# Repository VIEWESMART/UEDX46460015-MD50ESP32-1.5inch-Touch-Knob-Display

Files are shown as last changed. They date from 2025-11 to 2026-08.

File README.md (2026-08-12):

<h1 align = "center">UEDX46460015-MD50ESP32-1.5inch-Touch-Knob-Display</h1>

 * **[中文](./README_CN.md)**

<p align="center" width="90%">
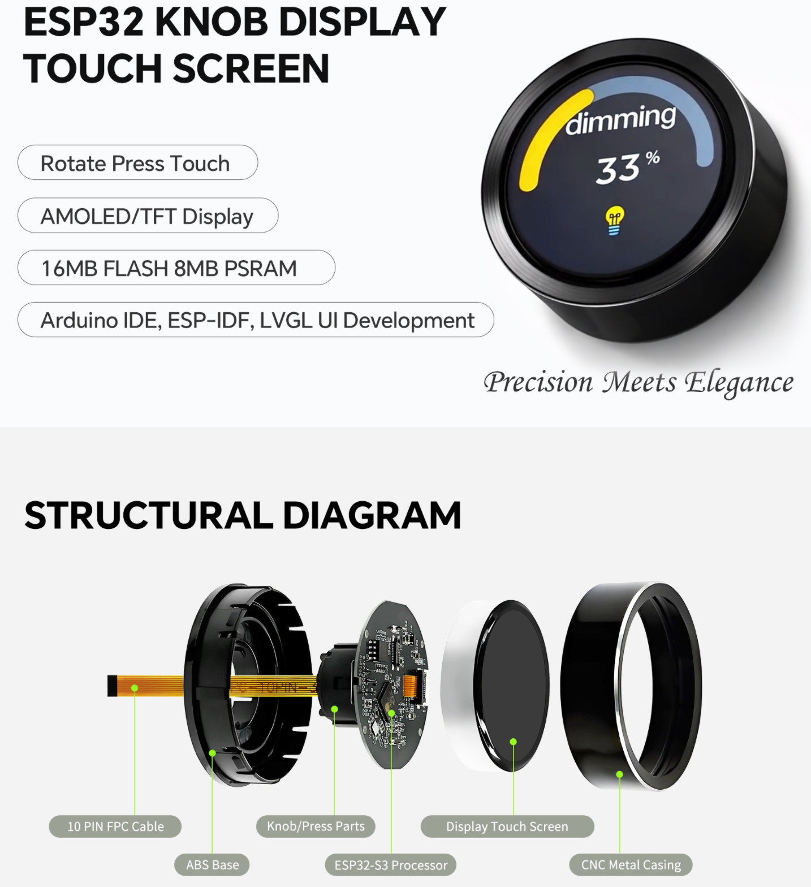
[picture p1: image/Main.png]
    
</p>

-   **UEDX46460015-MD50ET**
    ---
    The **Smart Knob Display** powered by **ESP32-S3**.  
    Featuring a 1.5-inch **466x466** AMOLED Display (QSPI), capacitive touch, rotary encoder and button.  
    Ideal for IoT control panels, smart home devices and industrial HMI.

## 1. Introduction

The **UEDX46460015-MD50ET** is a compact smart display module designed for knob‑style HMI applications.  
It combines a 1.5‑inch AMOLED display (466×466 pixels) with a capacitive touch panel, a rotary encoder and a hardware button.

Powered by the **ESP32‑S3‑R8** (16 MB Flash, 8 MB Octal PSRAM), it provides Wi‑Fi and Bluetooth 5 (LE) connectivity, and supports development with **Arduino**, **ESP‑IDF** and **PlatformIO**.

### 1.1 Product Features

* **Processor**:
    * **ESP32-S3**: Xtensa® Dual‑Core 32‑bit LX7 MCU @ 240 MHz.
    * Integrated 2.4 GHz Wi‑Fi (802.11 b/g/n) & Bluetooth 5 (LE).
* **Memory**:
    * **16 MB** Quad SPI Flash.
    * **8 MB** Octal SPI PSRAM.
* **Display & Touch**:
    * **Screen**: 1.5‑inch IPS AMOLED (466×466 Resolution).
    * **Interface**: QSPI.
    * **Driver IC**: CO5300AF‑42.
    * **Touch**: Capacitive Multi‑Touch (CST820) via I²C.
* **Peripherals**:
    * **Encoder**: Rotary encoder (PHA/PHB) for precise knob input.
    * **Button**: Hardware button (shared with BOOT).
    * **Connectivity**: USB‑C (USB/UART for programming and debugging), UART expansion (FPC).
    * **Expansion FPC**: Extra GPIO, 5V, GND, UART0.

### 1.2 Applications

* Smart Home Control Knobs
* Industrial Knob‑based HMI
* IoT Device Dials
* Wearable / Compact User Interfaces

---

## 2. Hardware Description

### 2.1 Module Overview

The main functional blocks of the board are:

| Component | Description |
| :--- | :--- |
| **ESP32‑S3‑R8** | Main SoC (16 MB Flash / 8 MB Octal PSRAM). |
| **1.5" AMOLED** | 466×466 pixel display driven by QSPI (CO5300AF‑42). |
| **CST820** | Capacitive touch controller (I²C). |
| **Rotary Encoder** | 2‑phase encoder (PHA/PHB) for knob rotation. |
| **Button** | BOOT button (also used for firmware download). |
| **USB‑C** | Programming, debug (UART via USB) and power (5V). |
| **FPC Connector** | Additional power, UART0 and UART2 signals. |

### 2.2 GPIO Definition (Pinout)

#### **Display (QSPI)**
| Display Pin | ESP32‑S3 Pin |
| :---: | :---: |
| CS | IO12 |
| PCLK | IO10 |
| DATA0 | IO13 |
| DATA1 | IO11 |
| DATA2 | IO14 |
| DATA3 | IO9 |
| RST | IO8 |
| BACKLIGHT | IO17 |

#### **Touch (CST820)**
| Touch Pin | ESP32‑S3 Pin |
| :---: | :---: |
| SDA | IO0 |
| SCL | IO1 |
| RST | IO3 |
| INT | IO4 |

#### **Button**
| Button Pin | ESP32‑S3 Pin |
| :---: | :---: |
| BOOT | IO0 |

#### **Encoder**
| Encoder Pin | ESP32‑S3 Pin |
| :---: | :---: |
| PHA | IO6 |
| PHB | IO5 |

#### **USB / UART**
| USB/UART Pin | ESP32‑S3 Pin |
| :---: | :---: |
| USB‑DN | IO19 |
| USB‑DP | IO20 |

#### **FPC Connector Pinout**
| FPC Pin | Adapter Signal | ESP32‑S3 Pin |
| :---: | :--- | :--- |
| 1 | 5V | 5V |
| 2 | PB7 | – |
| 3 | GND | GND |
| 4 | RX2 | GPIO40 |
| 5 | TX2 | GPIO39 |
| 6 | RX1 | U0RXD / GPIO44 |
| 7 | TX1 | U0TXD / GPIO43 |
| 8 | NC | CHIP‑EN |
| 9 | D+ (USB‑DP) | GPIO20 |
|10 | D‑ (USB‑DN) | GPIO19 |

### 2.3 Mechanical Dimensions

Refer to the product specification sheet for detailed dimensions.

---

## 3. Software

We provide comprehensive support for **Arduino**, **PlatformIO**, and **ESP‑IDF** frameworks, with pre‑ported **LVGL** examples.

### 3.1 Software Examples

Examples are available in the [GitHub Repository](https://github.com/VIEWESMART/ESP32-1.5inch-AMOLED-Knob) (examples folder).

| Framework | Example Path | Description |
| :---: | :--- | :--- |
| **Arduino** | `examples/arduino/gui/lvgl_v8` | **LVGL Benchmark**: Usage example of LVGL v8. Can be opened directly in Arduino IDE. |
| **ESP‑IDF** | `examples/esp_idf` | **LVGL port**: Example of porting and using LVGL in ESP‑IDF. |
| **PlatformIO** | `examples/platformio/lvgl_v8_port` | **LVGL v8 port**: Usage example of LVGL v8. |

### 3.2 Getting Started

#### 3.2.1 Preparation

* **Hardware**: UEDX46460015‑MD50ET Board, USB‑C Cable.
* **Software**: VS Code (ESP‑IDF v5.3+) or Arduino IDE (v2.0+) or VS Code (PlatformIO).
* **Libraries**: The following libraries are required for Arduino IDE and PlatformIO.

| Library | Version | Description |
| :--- | :--- | :--- |
| `ESP32_Display_Panel` | `1.0.3+` | By Espressif. Necessary to drive the screen. |
| `ESP32_IO_Expander` | *Arduino auto selection* | Dependency of `ESP32_Display_Panel`. |
| `esp-lib-utils` | *Arduino auto selection* | Dependency of `ESP32_Display_Panel`. |
| `lvgl` | `8.4.0` | Open‑source embedded graphics library. |

#### 3.2.2 ESP‑IDF Setup

For detailed procedures, please refer to the esp-idf example folder at [README.md](examples/ESP-IDF/UEDX46460015-MD50E-IDF/README.md) or [README_CN.md](examples/ESP-IDF/UEDX46460015-MD50E-IDF/README_CN.md). The general steps are as follows:

1.  **Open the example**  
    * Download the repository from GitHub (click the green "Code" button and select "Download ZIP", or clone it).  
    * Open the example folder (e.g., `examples/esp_idf`) using VS Code with the ESP‑IDF extension.
    
2.  **Compile and upload**  
    * Click the **build** icon to compile the project.  
    * Connect the board via USB‑C.  
    * Click the **upload** icon to flash the firmware.

#### 3.2.3 Arduino Setup([Novice tutorial](https://github.com/VIEWESMART/VIEWE-Tutorial/blob/main/Arduino%20Tutorial/Arduino%20Getting%20Started%20Tutorial.md))

1.  **Install Arduino IDE**  
    * Download and install the [Arduino IDE](https://www.arduino.cc/en/software) (v2.0+ recommended).

2.  **Install ESP32 Board Package**  
    * Open Arduino IDE and go to **File > Preferences**.  
    * Add the following URL in “Additional boards manager URLs”:  
      `https://espressif.github.io/arduino-esp32/package_esp32_index.json`  
    * Go to **Tools > Board > Boards Manager**, search for `esp32` by Espressif and install version **3.0.0+**.

3.  **Install Libraries**  
    * Go to **Sketch > Include Library > Library Manager**.  
    * Search for `ESP32_Display_Panel` by Espressif and install version **1.0.3+**. When prompted, click **INSTALL ALL** to install the dependencies.  
    * Install `lvgl` (version **8.4.0**).

4.  **Open Example**  
    * Navigate to **File > Examples > ESP32_Display_Panel**.  
    * Select **Arduino > gui > lvgl_v8 > simple_port**.

5.  **Select Board**  
    * Target: **ESP32S3 Dev Module**.  
    * Configure the following settings:
        * **Flash Size**: 16MB (128Mb)
        * **Partition Scheme**: 16M Flash (3MB APP/9.9MB FATFS)
        * **PSRAM**: **OPI PSRAM** (this is critical)

6.  **Configure the Supported Board**  
    * In the example, open the file `esp_panel_board_supported_conf.h`.  
    * Set the macro `ESP_PANEL_BOARD_DEFAULT_USE_SUPPORTED` to `1`.  
    * Locate the line `// #define BOARD_VIEWE_UEDX46460015_MD50ET` and uncomment it by removing the `//`.  
    * Ensure no other board definition is enabled at the same time.

7.  **Interface‑Specific Configuration**  
    * Since the board uses a **QSPI** interface, open `lv_conf.h` (or the example’s `lv_conf.h` equivalent) and set `LV_COLOR_16_SWAP` to `1`.  
    * **Do not** modify `LVGL_PORT_AVOID_TEARING_MODE` or `LVGL_PORT_ROTATION_DEGREE` (they are only relevant for RGB/MIPI displays).

8.  **Select Port and Upload**  
    * Connect the board, then go to **Tools > Port** and select the correct COM port.  
    * Click the **Verify** (✓) button to compile.  
    * Click the **Upload** (→) button to flash.

> [!TIP]
> **Configuration Tips**  
> * In `esp_panel_board_supported_conf.h`, ensure you uncomment: `#define BOARD_VIEWE_UEDX46460015_MD50ET`.  
> * Do not enable both `ESP_PANEL_BOARD_DEFAULT_USE_SUPPORTED` and `ESP_PANEL_BOARD_DEFAULT_USE_CUSTOM`.  
> * You cannot enable multiple board definitions at the same time.

#### 3.2.4 PlatformIO Setup

1.  **Open the example**  
    * Download the repository and open the `examples/platformio/lvgl_v8_port` folder in VS Code with the PlatformIO extension.

2.  **Select the Board Environment**  
    * Open the `platformio.ini` file.  
    * Change the `default_envs` line to `BOARD_VIEWE_UEDX46460015_MD50ET`.

3.  **Configure the Example**  
    * (QSPI interface) In `lv_conf.h`, set `LV_COLOR_16_SWAP` to `1`.  
    * Leave `LVGL_PORT_AVOID_TEARING_MODE` and `LVGL_PORT_ROTATION_DEGREE` untouched.

4.  **Compile and Upload**  
    * Click the **✓** (Compile) button.  
    * Connect the board, then click the **→** (Upload) button.
      
### 3.3 Firmware Download (Manual Flash)

If you need to flash a pre‑compiled binary manually:

1.  Open the “Flash Download Tool” (available in the tools folder or from Espressif’s website).
2.  Select the chip type (**ESP32‑S3**) and the correct download method.
3.  Load the firmware files from the `firmware` folder and configure the offsets as described in the firmware readme.
4.  Connect the board and start the download.  
    *If flashing fails, hold down the **BOOT** button while powering on, then retry.*

<p align="center" width="100%">
    example
    example
</p>

## FAQ

* Q. After reading the above tutorials, I still don't know how to build a programming environment. What should I do?
* A. If you still don't understand how to build an environment after reading the above tutorials, you can refer to the [VIEWE-FAQ]() document instructions to build it.

<br />

* Q. Why does Arduino IDE prompt me to update library files when I open it? Should I update them or not?
* A. Choose not to update library files. Different versions of library files may not be mutually compatible, so it is not recommended to update library files.

<br />

* Q. Why is there no serial data output on the "Uart" interface on my board? Is it defective and unusable?
* A. The default project configuration uses the USB interface as Uart0 serial output for debugging purposes. The "Uart" interface is connected to Uart0, so it won't output any data without configuration.<br />For PlatformIO users, please open the project file "platformio.ini" and modify the option under "build_flags = xxx" from "-D ARDUINO_USB_CDC_ON_BOOT=true" to "-D ARDUINO_USB_CDC_ON_BOOT=false" to enable external "Uart" interface.<br />For Arduino users, open the "Tools" menu and select "USB CDC On Boot: Disabled" to enable the external "Uart" interface.

<br />

* Q. Why is my board continuously failing to download the program?
* A. Please hold down the "BOOT" button and try downloading the program again.

## Information
[products specification](information/UEDX48480021-MD80E%20V3.3%20SPEC.pdf)

[Display Datasheet](information/UE021WV-RB40-L002B.pdf)

[button](information/6x6Silent%20switch.pdf)

[Encoder](information/C219783_%E6%97%8B%E8%BD%AC%E7%BC%96%E7%A0%81%E5%99%A8_EC28A1520401_%E8%A7%84%E6%A0%BC%E4%B9%A6_WJ239718.PDF)

[schematic](schematic/1.5%20MD50E%20SCH.V2.0_00.png)

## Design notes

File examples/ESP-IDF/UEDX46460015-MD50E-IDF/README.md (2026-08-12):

# UEDX46460015-MD50ET ESP-IDF Example

Open-source ESP-IDF example for the **UEDX46460015-MD50ET** 1.5" round AMOLED knob display (ESP32-S3): bring up LCD, touch, encoder/button, and run a SquareLine LVGL UI.

Board support is published as a registry BSP:

- BSP: [viewesmart/bsp_knob_15_md50et](https://components.espressif.com/components/viewesmart/bsp_knob_15_md50et) (`^1.0.2` recommended)
- Touch: [viewesmart/esp_lcd_touch_cst820](https://components.espressif.com/components/viewesmart/esp_lcd_touch_cst820) (pulled by the BSP)

[中文说明](./README_CN.md)

---

## Contents

1. [What you get](#what-you-get)
2. [Hardware](#hardware)
3. [Software setup (beginners)](#software-setup-beginners)
4. [Get this project](#get-this-project)
5. [Open and configure in VS Code](#open-and-configure-in-vs-code)
6. [First build](#first-build)
7. [Flash and monitor](#flash-and-monitor)
8. [What success looks like](#what-success-looks-like)
9. [Project layout](#project-layout)
10. [Dependencies](#dependencies)
11. [Application entry](#application-entry)
12. [Replace / edit the SquareLine UI](#replace--edit-the-squareline-ui)
13. [Choose LVGL 8 or 9](#choose-lvgl-8-or-9)
14. [Pinout](#pinout)
15. [BSP API summary](#bsp-api-summary)
16. [Troubleshooting](#troubleshooting)
17. [License and links](#license-and-links)

---

## What you get

After running this example you can:

- Show an LVGL UI on the 1.5" round AMOLED (demo UI included)
- Use the touchscreen
- Use the rotary encoder and the GPIO0 button
- Set panel brightness (0~100) through the BSP API

Verified with **ESP-IDF v5.5.4**, target **esp32s3**.

---

## Hardware

| Item | Spec |
|---|---|
| Module | UEDX46460015-MD50ET (folder name may say MD50E; same board family) |
| MCU | ESP32-S3 with **16 MB Flash + Octal PSRAM** (defaults assume this) |
| LCD | 1.5" round AMOLED, CO5300, QSPI |
| Touch | CST820, I2C |
| Input | Rotary encoder + button (GPIO0, often also Boot) |
| Cable | Data-capable USB cable |
| Host OS | Windows / macOS / Linux (steps below use Windows + VS Code) |

Display geometry (important):

| Use | Size |
|---|---|
| Driver / LVGL buffer | **472 x 466** |
| SquareLine design | **466 x 466** |
| `esp_lcd_panel_set_gap()` | **Do not use** |

---

## Software setup (beginners)

Recommended: **Visual Studio Code + Espressif IDF extension**, and install the toolchain with **EIM (ESP-IDF Installation Manager / Espressif Installation Manager)**. This is the current official flow and replaces the older "Configure ESP-IDF extension" wizard.

Official docs:

- [Install ESP-IDF and Tools (VS Code extension)](https://docs.espressif.com/projects/vscode-esp-idf-extension/en/latest/installation.html)
- [ESP-IDF Installation Manager](https://docs.espressif.com/projects/idf-im-ui/en/latest/)

### 1. Install VS Code

Download and install from [https://code.visualstudio.com/](https://code.visualstudio.com/).

### 2. Install the Espressif IDF extension

1. Open Extensions (`Ctrl+Shift+X` on Windows/Linux, `Shift+Command+X` on macOS).
2. Search for **ESP-IDF** or **Espressif IDF**.
3. Install the extension by **Espressif Systems**.
4. If a setup prompt appears, you can dismiss it and continue with EIM below.

### 3. Install ESP-IDF with EIM (>= 5.5)

EIM installs the ESP-IDF framework and required tools (compiler, CMake, Ninja, OpenOCD, etc.). After that, the VS Code extension auto-discovers installs via EIM's manifest file.

#### 3.1 Open EIM from VS Code (recommended)

1. Open the Command Palette (`Ctrl+Shift+P` / `Shift+Command+P`).
2. Run **ESP-IDF: Open ESP-IDF Installation Manager**.
3. Wait for the loading notification; EIM should start.
4. On a desktop machine, EIM usually opens as a **GUI** wizard—follow the on-screen steps.
5. Choose an **ESP-IDF version**:
   - This project needs **>= 5.5**
   - Recommended: **v5.5.4** (verified with this repo)
6. Pick an install path (short path, **no spaces**, ASCII preferred).
7. Confirm and wait for download/install (first run can take a while). In China, prefer Espressif download mirrors when offered.
8. Return to VS Code when finished.

#### 3.2 Select the active ESP-IDF version

If multiple versions are installed:

1. Command Palette -> **ESP-IDF: Select Current ESP-IDF Version**
2. Select the version for this project (for example **5.5.4**)
3. The extension stores the setup for the current workspace

> Default `eim_idf.json` locations: `C:\Espressif\tools\eim_idf.json` on Windows, `$HOME/.espressif/tools/eim_idf.json` on macOS/Linux. Usually no manual edit is needed; if discovery fails, check `idf.eimIdfJsonPath` in VS Code settings.

#### 3.3 Verify the install

1. Run **ESP-IDF: Doctor Command**
2. Fix any red errors before continuing
3. Confirm the status bar shows a valid ESP-IDF version

#### 3.4 Optional: install EIM standalone

You can also install EIM first, then use it to install ESP-IDF:

1. Open the [ESP-IDF Installation Manager docs / download](https://docs.espressif.com/projects/idf-im-ui/en/latest/)
2. Install EIM for your OS
3. Use EIM to install **ESP-IDF >= 5.5** (recommended **5.5.4**)
4. In VS Code, run **ESP-IDF: Select Current ESP-IDF Version** and pick that install

#### 3.5 Remote / headless note

In **SSH, WSL, Dev Containers, Codespaces**, or browser-based VS Code, the extension may run a terminal wizard (for example `eim wizard`) instead of the GUI. Follow the terminal prompts. See the official installation docs for details.

### 4. USB serial driver (Windows)

If no `COMx` port appears, install the USB-UART / USB-JTAG driver for your board (CP210x, CH340, Espressif USB-JTAG, etc.), then replug the cable.

---

## Get this project

**Option A: git clone**

```bash
git clone <this-repo-url>
cd UEDX46460015-MD50E-IDF
```

**Option B: Download ZIP**

1. GitHub -> **Code -> Download ZIP**.
2. Extract to a short ASCII path, e.g. `D:\work\UEDX46460015-MD50E-IDF`.
3. In VS Code, open that root folder (must contain `main/` and root `CMakeLists.txt`).

---

## Open and configure in VS Code

1. **File -> Open Folder...** and select the project root.
2. Trust the workspace if prompted.
3. Check the status bar for: ESP-IDF version, target **esp32s3**, and serial port.
4. Set target: Command Palette -> **ESP-IDF: Set Espressif device target** -> `esp32s3`.
5. Select port: **ESP-IDF: Select port to use**.

If you previously built for another target, delete `build/` before rebuilding.

---

## First build

### UI buttons

Click **Build** (or run **ESP-IDF: Build your project**).

The first build will:

1. Download dependencies into `managed_components/` from the ESP Component Registry
2. Compile IDF + LVGL + UI assets (can take several minutes)

Success ends with:

```text
Project build complete.
```

### CLI

```bash
cd /path/to/UEDX46460015-MD50E-IDF
idf.py set-target esp32s3
idf.py build
```

After a successful resolve you should see folders such as:

- `managed_components/viewesmart__bsp_knob_15_md50et`
- `managed_components/viewesmart__esp_lcd_touch_cst820`
- `managed_components/espressif__esp_lcd_co5300`
- `managed_components/espressif__esp_lvgl_adapter`
- `managed_components/lvgl__lvgl`

Do **not** hand-edit `managed_components/` or `dependencies.lock`.

---

## Flash and monitor

1. Connect USB and select the correct port.
2. If connect fails, hold **Boot** while starting flash (board-dependent).
3. Click **Flash**, then **Monitor** (or Flash and Monitor).

CLI example:

```bash
idf.py -p PORT flash monitor
```

Exit monitor: `Ctrl+]`.

---

## What success looks like

1. The round display shows the demo UI.
2. Serial log shows BSP init success (resolution / LVGL major).
3. Touch, encoder, and button interact with the UI.

If not, see [Troubleshooting](#troubleshooting).

---

## Project layout

```text
UEDX46460015-MD50E-IDF/
├── CMakeLists.txt
├── dependencies.lock           # auto-generated lockfile
├── partitions.csv              # custom table (~3MB factory)
├── sdkconfig / sdkconfig.defaults*
├── README.md / README_CN.md
├── main/
│   ├── CMakeLists.txt
│   ├── idf_component.yml       # pulls BSP + pins LVGL major
│   ├── main.c
│   └── ui/                     # SquareLine export
└── managed_components/         # downloaded deps (do not edit)
```

This example does **not** keep a local copy of the BSP under `components/`. It pulls `viewesmart/bsp_knob_15_md50et` from the registry.

---

## Dependencies

From `main/idf_component.yml`:

```yaml
dependencies:
  idf: ">=5.5"
  viewesmart/bsp_knob_15_md50et: "^1.0.2"
  lvgl/lvgl:
    version: "^8.3.11"
    public: true
```

`main/CMakeLists.txt` links the managed component as:

```cmake
REQUIRES
    viewesmart__bsp_knob_15_md50et
    lvgl
    esp_lvgl_adapter
```

---

## Application entry

See `main/main.c`:

```c
#include "bsp_knob_15_md50et.h"
#include "ui.h"

void app_main(void)
{
    bsp_knob_15_md50et_handles_t handles = {0};
    ESP_ERROR_CHECK(bsp_knob_15_md50et_init(&handles));

    bsp_knob_15_md50et_register_knob_cb(LVGL_knob_event);
    bsp_knob_15_md50et_register_button_cb(LVGL_button_event);

    if (bsp_knob_15_md50et_lock(-1) == ESP_OK) {
        ui_init();
        bsp_knob_15_md50et_unlock();
    }
}
```

Rules:

1. Call `bsp_knob_15_md50et_init()` first.
2. All LVGL calls must be between `lock` / `unlock`.
3. If a knob/button callback touches LVGL, lock there too.

Brightness:

```c
ESP_ERROR_CHECK(bsp_knob_15_md50et_set_brightness(80));  /* 0~100 */
```

---

## Replace / edit the SquareLine UI

1. Create/open a SquareLine project at **466 x 466**.
2. Use the same LVGL major as this repo (demo is **LVGL 8.x**).
3. Export into `main/ui/`.
4. `main/CMakeLists.txt` already compiles `ui/**/*.c`.
5. Do **not** shift widgets to "fix" centering; driver width is 472 and `set_gap` is unused.
6. Rebuild and flash.

If the app no longer fits flash, confirm custom `partitions.csv` (3MB `factory`) is enabled.

---

## Choose LVGL 8 or 9

The BSP accepts LVGL 8/9, but your UI must match one major.

```yaml
lvgl/lvgl:
  version: "^8.3.11"   # current demo
  # version: "^9"      # only if UI is exported for LVGL 9
  public: true
```

After switching majors, delete `managed_components/lvgl__lvgl`, `dependencies.lock`, and `build/`, then rebuild and replace `main/ui/`.

---

## Pinout

From `bsp_knob_15_md50et_board.h`:

| Function | GPIO |
|---|---|
| LCD CS / PCLK / D0-D3 | 12 / 10 / 13, 11, 14, 9 |
| LCD RST | 8 |
| Panel power (HIGH before LCD init) | 17 |
| Touch SCL / SDA / RST / INT | 3 / 1 / 2 / 4 |
| Encoder A / B | 6 / 5 |
| Button | 0 |

---

## BSP API summary

| API | Description |
|-----|---|
| `bsp_knob_15_md50et_init()` | Init power, LCD, touch, LVGL, knob, button |
| `bsp_knob_15_md50et_lock` / `unlock` | LVGL lock |
| `bsp_knob_15_md50et_set_brightness(0~100)` | Panel brightness (QSPI-safe) |
| `bsp_knob_15_md50et_backlight_on` / `off` | GPIO17 panel power |
| `bsp_knob_15_md50et_register_knob_cb` | Knob callback |
| `bsp_knob_15_md50et_register_button_cb` | Button callback |

Full docs:

- Registry: [viewesmart/bsp_knob_15_md50et](https://components.espressif.com/components/viewesmart/bsp_knob_15_md50et)
- Source: [GitHub bsp_knob_15_md50et](https://github.com/VIEWESMART/Viewe-esp32-components/tree/main/bsp/bsp_knob_15_md50et)

---

## Troubleshooting

### Environment / build

| Symptom | What to try |
|---|---|
| Cannot open EIM / Installation Manager | Update the **Espressif IDF** extension and reload VS Code; or install standalone [EIM](https://docs.espressif.com/projects/idf-im-ui/en/latest/) first |
| EIM download slow / failed | Switch network/proxy; prefer Espressif mirrors; allowlist Espressif install folders in antivirus |
| Extension cannot find installed IDF | Run **ESP-IDF: Select Current ESP-IDF Version**; check `eim_idf.json` or `idf.eimIdfJsonPath` |
| `idf.py` / extension not ready | Install IDF via EIM, then **ESP-IDF: Select Current ESP-IDF Version** and **ESP-IDF: Doctor Command**; use the extension IDF terminal |
| Stale config after target change | Delete `build/` and rebuild |
| Component not found / solve failed | Check registry access; confirm BSP version `^1.0.2` exists |
| button / adapter version conflict | Use BSP **>= 1.0.2**; delete `dependencies.lock` + `managed_components/` |
| App partition too small | Enable custom `partitions.csv` (3M factory) |
| First build very slow | Normal for LVGL + image assets |

### Flash / serial

| Symptom | What to try |
|---|---|
| No COM port | Data cable, USB driver, another port |
| Failed to connect | Hold Boot while flashing; close other serial apps |
| Monitor garbage | Match monitor baud rate (often 115200) |

### Display / touch / input

| Symptom | What to try |
|---|---|
| Black screen | Keep board CO5300 init table; GPIO17 is driven high before LCD init inside BSP |
| Left blank / right green line | Keep **472x466**, no `set_gap` |
| Brightness unchanged | Use `bsp_knob_15_md50et_set_brightness()`, do not raw-write `0x51` on QSPI |
| Touch dead | Check CST820 init logs / I2C |
| Knob/button dead | Ensure callbacks registered; lock before LVGL in callbacks |

### Clean rebuild

Delete:

```text
build/
managed_components/
dependencies.lock
```

Then:

```bash
idf.py set-target esp32s3
idf.py build
```

---

## License and links

- Example app code: see SPDX headers in source files (e.g. `main/main.c` is CC0-1.0)
- BSP / touch components: Apache-2.0 (see component repos)
- Other third-party components: their own licenses

Links:

- BSP: [viewesmart/bsp_knob_15_md50et](https://components.espressif.com/components/viewesmart/bsp_knob_15_md50et)
- Touch: [viewesmart/esp_lcd_touch_cst820](https://components.espressif.com/components/viewesmart/esp_lcd_touch_cst820)
- Component monorepo: [Viewe-esp32-components](https://github.com/VIEWESMART/Viewe-esp32-components)
- ESP-IDF docs: [https://docs.espressif.com/projects/esp-idf/](https://docs.espressif.com/projects/esp-idf/)
- VS Code install guide (EIM): [Install ESP-IDF and Tools](https://docs.espressif.com/projects/vscode-esp-idf-extension/en/latest/installation.html)
- EIM docs: [ESP-IDF Installation Manager](https://docs.espressif.com/projects/idf-im-ui/en/latest/)
- VS Code extension overview: [Espressif IDF Extension](https://docs.espressif.com/projects/vscode-esp-idf-extension/en/latest/)

Issues and PRs are welcome. If you are new to ESP-IDF, finish **setup -> build -> flash** once before changing the UI.

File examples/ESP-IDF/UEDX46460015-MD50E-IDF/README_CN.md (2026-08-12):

# UEDX46460015-MD50ET ESP-IDF 示例工程

本仓库是 **UEDX46460015-MD50ET**（1.5 寸圆形 AMOLED 旋钮屏，ESP32-S3）的开源示例，展示如何用 ESP-IDF 点亮屏幕、触摸、旋钮/按键，并运行 SquareLine 导出的 LVGL UI。

板级驱动已封装为组件仓库中的 BSP：

- BSP：[viewesmart/bsp_knob_15_md50et](https://components.espressif.com/components/viewesmart/bsp_knob_15_md50et)（建议 `^1.0.2`）
- 触摸：[viewesmart/esp_lcd_touch_cst820](https://components.espressif.com/components/viewesmart/esp_lcd_touch_cst820)（由 BSP 自动拉取）

[English](./README.md)

---

## 目录

1. [你能得到什么](#你能得到什么)
2. [硬件准备](#硬件准备)
3. [软件环境准备（新手必看）](#软件环境准备新手必看)
4. [获取本工程](#获取本工程)
5. [用 VS Code 打开并配置](#用-vs-code-打开并配置)
6. [第一次编译](#第一次编译)
7. [烧录与串口监视](#烧录与串口监视)
8. [成功时你会看到什么](#成功时你会看到什么)
9. [工程目录说明](#工程目录说明)
10. [依赖说明](#依赖说明)
11. [示例代码入口](#示例代码入口)
12. [替换 / 修改 SquareLine UI](#替换--修改-squareline-ui)
13. [选择 LVGL 8 或 9](#选择-lvgl-8-或-9)
14. [引脚一览](#引脚一览)
15. [BSP API 摘要](#bsp-api-摘要)
16. [常见问题排查](#常见问题排查)
17. [许可证与相关链接](#许可证与相关链接)

---

## 你能得到什么

跑通本示例后，你可以：

- 在 1.5" 圆形 AMOLED 上显示 LVGL 界面（本仓库自带演示 UI）
- 使用触摸屏点按 UI
- 使用旋钮左右旋转、按键（GPIO0）触发 UI 事件
- 通过 BSP API 调节面板亮度（0~100）

本工程已在 **ESP-IDF v5.5.4**、目标芯片 **esp32s3** 上验证。

---

## 硬件准备

| 项目 | 说明 |
|---|---|
| 模组 | UEDX46460015-MD50ET（文件夹名可能写作 MD50E，指同一款板） |
| MCU | ESP32-S3，**16 MB Flash + Octal PSRAM**（本工程默认按此配置） |
| 屏幕 | 1.5" 圆形 AMOLED，驱动芯片 CO5300，接口 QSPI |
| 触摸 | CST820，I2C |
| 输入 | 旋转编码器 + 按键（GPIO0，通常也是 Boot 键） |
| 数据线 | 能传数据的 USB 线（仅充电线无法下载） |
| 电脑 | Windows / macOS / Linux 均可（下文以 Windows + VS Code 为例） |

显示分辨率约定（很重要，改错会出现绿边/留白）：

| 用途 | 分辨率 |
|---|---|
| 驱动 / LVGL 显示缓冲 | **472 × 466** |
| SquareLine 工程设计尺寸 | **466 × 466** |
| `esp_lcd_panel_set_gap()` | **不要调用** |

---

## 软件环境准备（新手必看）

推荐使用 **Visual Studio Code + Espressif IDF 扩展**，并通过 **EIM（ESP-IDF Installation Manager / Espressif Installation Manager）** 安装 ESP-IDF 与工具链。这是当前官方推荐方式，比旧的 “Configure ESP-IDF extension” 向导更统一、更稳定。

官方说明可参考：

- [Install ESP-IDF and Tools（VS Code 扩展文档）](https://docs.espressif.com/projects/vscode-esp-idf-extension/en/latest/installation.html)
- [ESP-IDF Installation Manager](https://docs.espressif.com/projects/idf-im-ui/en/latest/)

### 1. 安装 VS Code

1. 打开 [https://code.visualstudio.com/](https://code.visualstudio.com/) 下载并安装。
2. 安装完成后打开 VS Code。

### 2. 安装 Espressif IDF 扩展

1. 左侧点 **扩展（Extensions）**，或按 `Ctrl+Shift+X`（macOS：`Shift+Command+X`）。
2. 搜索 **ESP-IDF** 或 **Espressif IDF**。
3. 安装发布者名为 **Espressif Systems** 的扩展。
4. 安装完成后如弹出配置提示，可先关闭，下一步用 EIM 正式安装。

### 3. 用 EIM 安装 ESP-IDF（>= 5.5）

EIM 会安装 ESP-IDF 框架以及编译/烧录所需工具（编译器、CMake、Ninja、OpenOCD 等）。装好后，VS Code 扩展会自动读取 EIM 生成的清单文件并发现已安装版本。

#### 3.1 从 VS Code 打开 EIM（推荐）

1. 按 `Ctrl+Shift+P`（macOS：`Shift+Command+P`）打开命令面板。
2. 输入并选择：**ESP-IDF: Open ESP-IDF Installation Manager**。
3. 稍等片刻，会看到加载提示，随后启动 EIM。
4. 在桌面环境下，EIM 通常以 **图形界面（GUI）** 打开；按窗口提示一步步操作即可。
5. 选择要安装的 **ESP-IDF 版本**：
   - 本工程要求 **>= 5.5**
   - 建议安装 **v5.5.4**（本仓库验证版本）
6. 按提示选择安装路径（路径尽量短、**不要有空格**、尽量纯英文）。
7. 确认后开始下载与安装。首次安装可能较久，请保持网络畅通；国内网络可优先使用乐鑫下载源（若 EIM / 文档提供 Download 选项）。
8. 安装完成后再回到 VS Code。

#### 3.2 选择当前使用的 ESP-IDF 版本

若你安装了多个版本：

1. 命令面板执行：**ESP-IDF: Select Current ESP-IDF Version**
2. 在列表中选择本工程要用的版本（例如 **5.5.4**）
3. 扩展会把当前工程需要的环境变量配置好

> Windows 上 EIM 清单默认通常在 `C:\Espressif\tools\eim_idf.json`；macOS/Linux 通常在 `$HOME/.espressif/tools/eim_idf.json`。一般无需手改；若扩展找不到安装，可在 VS Code 设置里检查 `idf.eimIdfJsonPath`。

#### 3.3 检查安装是否正常

1. 命令面板执行：**ESP-IDF: Doctor Command**
2. 查看输出，确认没有红色错误
3. 也可看 VS Code 状态栏是否显示已识别的 ESP-IDF 版本

#### 3.4 可选：单独下载 EIM

如果不想从扩展内启动，也可以先安装独立版 EIM，再用它安装 ESP-IDF：

1. 打开 [ESP-IDF Installation Manager 文档 / 下载页](https://docs.espressif.com/projects/idf-im-ui/en/latest/)
2. 按系统选择安装方式（Windows / macOS / Linux；也可用包管理器或直接下载）
3. 运行 EIM，安装 **ESP-IDF >= 5.5**（建议 5.5.4）
4. 回到 VS Code，执行 **ESP-IDF: Select Current ESP-IDF Version** 选中刚装的版本

#### 3.5 远程 / 无界面环境说明

若你在 **SSH、WSL、Dev Containers、Codespaces** 等环境中使用 VS Code，扩展可能无法弹出 EIM 图形界面，而会改走终端向导（例如 `eim wizard`）。按终端提示选择版本并完成安装即可。详见官方安装文档。

### 4. 准备驱动（Windows 常见）

- 多数板子使用板载 USB-UART 或 USB-JTAG。
- 若设备管理器里没有端口（`COMx`），请安装对应 USB 驱动（常见为 Silicon Labs CP210x、WCH CH340、或乐鑫 USB-JTAG 驱动）。
- 安装后重新插拔 USB，确认出现 `COMx`。

---

## 获取本工程

任选一种方式：

**方式 A：Git 克隆（推荐）**

```bash
git clone <本仓库地址>
cd UEDX46460015-MD50E-IDF
```

**方式 B：下载 ZIP**

1. 在 GitHub 页面点击 **Code -> Download ZIP**。
2. 解压到不包含中文空格特殊符号的路径，例如：`D:\work\UEDX46460015-MD50E-IDF`。
3. 用 VS Code 打开解压后的**根目录**（能看到 `main/` 和根目录 `CMakeLists.txt`）。

> 路径尽量短、纯英文，可减少 Windows 下路径过长导致的编译问题。

---

## 用 VS Code 打开并配置

### 1. 打开文件夹

1. VS Code：**文件 -> 打开文件夹...**
2. 选择本工程根目录。
3. 若提示“是否信任”，选择信任。

### 2. 确认状态栏三项

打开后，底部状态栏应能看到类似信息：

1. **ESP-IDF 版本**（如 5.5.4）
2. **目标芯片**：必须是 `esp32s3`
3. **串口**：如 `COM5`（插上板子后选择）

### 3. 设置目标芯片（第一次很重要）

1. `Ctrl+Shift+P`
2. 选择：**ESP-IDF: Set Espressif device target**
3. 选择 **esp32s3**
4. 等待配置完成（会生成/更新 `sdkconfig`）

> 若以前用别的芯片编译过，切换 target 后建议删掉 `build/` 再编译。

### 4. 选择串口

1. `Ctrl+Shift+P`
2. 选择：**ESP-IDF: Select port to use**
3. 选中板子对应的 `COMx`

---

## 第一次编译

### 图形界面（推荐）

1. 点击 VS Code 底部或侧边的 **Build**（🔧图标），或命令面板执行 **ESP-IDF: Build your project**。
2. 第一次编译会做两件耗时的事：
   - 从 [ESP Component Registry](https://components.espressif.com/) 下载依赖到 `managed_components/`
   - 编译 IDF + LVGL + UI 资源（可能 3 分钟左右，取决于电脑）
3. 成功时终端末尾会出现类似：

```text
Project build complete.
```

### 命令行方式

在已 `export` ESP-IDF 环境的终端中：

```bash
cd /path/to/UEDX46460015-MD50E-IDF
idf.py set-target esp32s3
idf.py build
```

### 第一次编译常见现象（正常）

| 现象 | 说明 |
|---|---|
| 提示 Solving dependencies / Processing dependencies | 正在解析并下载组件，请等待 |
| 生成 `managed_components/`、`dependencies.lock` | 正常，**不要手改**这些内容 |
| 下载很慢或超时 | 检查网络；可稍后重试 `idf.py build` |

成功拉取后，你应能在 `managed_components/` 看到例如：

- `viewesmart__bsp_knob_15_md50et`
- `viewesmart__esp_lcd_touch_cst820`
- `espressif__esp_lcd_co5300`
- `espressif__esp_lvgl_adapter`
- `espressif__button` / `espressif__knob`
- `lvgl__lvgl`

---

## 烧录与串口监视

### 烧录前检查

1. USB 已连接，串口已选对。
2. 若烧录时提示连接失败：按住板上 **Boot** 键再点烧录，或进入下载模式后再松手（视硬件而定）。
3. 关闭占用串口的其他软件（串口助手、旧 Monitor 等）。

### 图形界面

1. 点击 **Flash（⚡）** 烧录。
2. 点击 **Monitor（显示器图标）** 打开串口日志。
3. 也可使用组合按钮 **Flash and Monitor（火苗图标）**。

### 命令行

把 `PORT` 换成你的串口，例如 Windows 的 `COM5`，Linux 的 `/dev/ttyUSB0`：

```bash
idf.py -p PORT flash monitor
```

退出监视器：`Ctrl+]`。

---

## 成功时你会看到什么

1. 屏幕点亮，显示本仓库演示 UI（SquareLine 界面）。
2. 串口日志中有 BSP 初始化成功信息（含分辨率、LVGL 版本等）。
3. 触摸可点击；旋钮左右转、按键可触发 UI 中对应逻辑。

若黑屏 / 花屏 / 无触摸，请先看文末 [常见问题排查](#常见问题排查)。

---

## 工程目录说明

```text
UEDX46460015-MD50E-IDF/
├── CMakeLists.txt              # 工程入口 CMake
├── dependencies.lock           # 组件版本锁定（自动生成，勿手改）
├── partitions.csv              # 自定义分区表（factory 约 3MB）
├── sdkconfig                   # 本地当前配置（编译后生成/修改）
├── sdkconfig.defaults          # 默认配置（LVGL、分区表等）
├── sdkconfig.defaults.esp32s3  # ESP32-S3：Flash/PSRAM 等
├── README.md                   # 英文说明
├── README_CN.md                # 中文说明（本文件）
├── main/                       # 应用代码
│   ├── CMakeLists.txt          # 编译 main.c + ui 源文件
│   ├── idf_component.yml       # 声明 BSP / LVGL 等依赖
│   ├── main.c                  # app_main 入口
│   └── ui/                     # SquareLine 导出的 UI
│       ├── ui.c / ui.h
│       ├── screens/
│       ├── images/
│       └── ...
└── managed_components/         # 组件管理器自动下载（勿手改，可删后重建）
    ├── viewesmart__bsp_knob_15_md50et/
    ├── viewesmart__esp_lcd_touch_cst820/
    └── ...
```

说明：

- **不要**把 BSP 再复制一份到 `components/`，除非你明确要改 BSP 源码做本地调试。
- 本示例已通过 `main/idf_component.yml` 从注册表拉取 BSP。

---

## 依赖说明

`main/idf_component.yml` 关键内容大致如下：

```yaml
dependencies:
  idf: ">=5.5"
  viewesmart/bsp_knob_15_md50et: "^1.0.2"
  lvgl/lvgl:
    version: "^8.3.11"   # 与当前演示 UI（LVGL 8）匹配
    public: true
```

| 依赖 | 作用 |
|---|---|
| `viewesmart/bsp_knob_15_md50et` | 板级初始化：LCD / 触摸 / LVGL adapter / 旋钮 / 按键 / 亮度 |
| `lvgl/lvgl` | GUI 库（主版本必须与 UI 导出一致） |
| BSP 传递依赖 | CO5300、CST820、`esp_lvgl_adapter`、`button`、`knob` 等会自动下载 |

`main/CMakeLists.txt` 中通过下面名称链接 managed 组件（双下划线是命名空间规则）：

```cmake
REQUIRES
    viewesmart__bsp_knob_15_md50et
    lvgl
    esp_lvgl_adapter
```

---

## 示例代码入口

核心逻辑在 `main/main.c`：

```c
#include "bsp_knob_15_md50et.h"
#include "ui.h"

void app_main(void)
{
    bsp_knob_15_md50et_handles_t handles = {0};
    ESP_ERROR_CHECK(bsp_knob_15_md50et_init(&handles));

    bsp_knob_15_md50et_register_knob_cb(LVGL_knob_event);
    bsp_knob_15_md50et_register_button_cb(LVGL_button_event);

    if (bsp_knob_15_md50et_lock(-1) == ESP_OK) {
        ui_init();
        bsp_knob_15_md50et_unlock();
    }
}
```

规则：

1. 先 `bsp_knob_15_md50et_init()`。
2. 所有 LVGL API（含 `ui_init()`、改控件）必须夹在 `lock` / `unlock` 之间。
3. 旋钮/按键回调里如果要操作 LVGL，同样先 `lock`。

调节亮度示例：

```c
ESP_ERROR_CHECK(bsp_knob_15_md50et_set_brightness(80));  /* 0~100 */
```

---

## 替换 / 修改 SquareLine UI

1. 打开 SquareLine Studio，新建或打开工程，分辨率设为 **466 × 466**。
2. LVGL 版本选择与本工程一致（当前示例为 **LVGL 8.x**）。
3. 导出到 `main/ui/`（覆盖生成文件时注意保留你自己改过的事件文件，如有）。
4. 本工程 `main/CMakeLists.txt` 已用通配符编译 `ui/**/*.c`，一般无需改 CMake。
5. **不要**为了“居中对齐”去整体平移控件坐标：驱动宽度是 472，且不使用 `set_gap`；SquareLine 继续按 466×466 设计即可。
6. 重新 `build` / `flash`。

若 UI 资源变大导致烧录报分区不足：确认 `sdkconfig` 使用了自定义 `partitions.csv`（本仓库默认 `factory` 为 **3MB**）。

---

## 选择 LVGL 8 或 9

BSP 支持 LVGL 8/9，但**应用 UI 只能选一个主版本**。

在 `main/idf_component.yml`：

```yaml
lvgl/lvgl:
  version: "^8.3.11"   # 当前演示 UI
  # version: "^9"      # 仅当你的 UI 按 LVGL 9 导出时启用
  public: true
```

切换主版本后建议：

1. 删除 `managed_components/lvgl__lvgl`
2. 删除 `dependencies.lock`
3. 删除 `build/`
4. 重新 `idf.py set-target esp32s3`（如需要）并 `idf.py build`
5. 同步替换 `main/ui/` 为对应主版本导出的代码

---

## 引脚一览

定义在 BSP 头文件 `bsp_knob_15_md50et_board.h`（位于 managed 组件 include 目录）：

| 功能 | GPIO |
|---|---|
| LCD CS | 12 |
| LCD PCLK | 10 |
| LCD D0 / D1 / D2 / D3 | 13 / 11 / 14 / 9 |
| LCD RST | 8 |
| 面板供电（须在 LCD init 前为高） | 17 |
| 触摸 SCL / SDA | 3 / 1 |
| 触摸 RST / INT | 2 / 4 |
| 编码器 A / B | 6 / 5 |
| 按键 | 0 |

---

## BSP API 摘要

| API | 说明 |
|-----|---|
| `bsp_knob_15_md50et_init()` | 初始化供电、LCD、触摸、LVGL、旋钮、按键 |
| `bsp_knob_15_md50et_lock` / `unlock` | LVGL 线程安全锁 |
| `bsp_knob_15_md50et_set_brightness(0~100)` | 面板亮度（QSPI 下请用此 API） |
| `bsp_knob_15_md50et_backlight_on` / `off` | GPIO17 面板供电开关 |
| `bsp_knob_15_md50et_register_knob_cb` | 旋钮回调（`KNOB_LEFT` / `KNOB_RIGHT`） |
| `bsp_knob_15_md50et_register_button_cb` | 按键回调（按下/抬起/长按保持） |

更完整的说明见组件文档：

- 注册表：[viewesmart/bsp_knob_15_md50et](https://components.espressif.com/components/viewesmart/bsp_knob_15_md50et)
- 源码：[GitHub bsp_knob_15_md50et](https://github.com/VIEWESMART/Viewe-esp32-components/tree/main/bsp/bsp_knob_15_md50et)

---

## 常见问题排查

### A. 环境 / 编译类

| 现象 | 处理建议 |
|---|---|
| 打不开 EIM / Installation Manager | 确认已安装最新 **Espressif IDF** 扩展；更新扩展后重开 VS Code；也可先装独立版 [EIM](https://docs.espressif.com/projects/idf-im-ui/en/latest/) |
| EIM 下载很慢或失败 | 换网络 / 代理；优先使用乐鑫下载源；杀毒软件放行 Espressif 安装目录 |
| 扩展找不到已安装的 IDF | 执行 **ESP-IDF: Select Current ESP-IDF Version**；检查 `eim_idf.json` 或设置 `idf.eimIdfJsonPath` |
| 找不到 `idf.py` / 扩展未激活 | 用 EIM 安装 IDF 后执行 **ESP-IDF: Select Current ESP-IDF Version**，再跑 **ESP-IDF: Doctor Command**；用扩展自带的 IDF 终端 |
| `Set target` 后编译错误残留 | 删除 `build/` 再编译 |
| `Version solving failed` / 找不到组件 | 检查网络能否访问 components.espressif.com；确认 `main/idf_component.yml` 中 BSP 版本存在（如 `^1.0.2`） |
| 依赖冲突（button / adapter 版本） | 使用 BSP **>= 1.0.2**；删除 `dependencies.lock` 与 `managed_components/` 后重编 |
| 编译报 app 太大 / 分区不够 | 确认启用自定义分区 `partitions.csv`（3M factory） |
| 第一次特别慢 | 正常；LVGL + 图片资源编译耗时 |

### B. 烧录 / 串口类

| 现象 | 处理建议 |
|---|---|
| 没有 COM 口 | 换数据线、装 USB 驱动、换 USB 口 |
| `Failed to connect` | 按住 Boot 再烧录；确认波特率/驱动；关闭占用串口的程序 |
| Monitor 乱码 | 确认监视波特率与工程一致（常见 115200） |

### C. 显示 / 触摸 / 输入类

| 现象 | 处理建议 |
|---|---|
| 黑屏 | 确认是本板固件；GPIO17 已在 BSP 内于 LCD init 前拉高；勿替换掉板级 CO5300 初始化表 |
| 左边留白 / 右边绿线 | 驱动分辨率保持 **472×466**，**不要** `set_gap` |
| 亮度没变化 | 调用 `bsp_knob_15_md50et_set_brightness()`，不要对 QSPI 直接写 `0x51` |
| 触摸无反应 | 查看日志是否 CST820 初始化失败；检查 I2C 接线/模组型号 |
| 旋钮/按键无反应 | 确认已 `register_*_cb`；回调里操作 LVGL 前先 `lock` |

### D. 想“干净重来”

在工程根目录删除后重编（会重新下载组件）：

```text
build/
managed_components/
dependencies.lock
```

然后：

```bash
idf.py set-target esp32s3
idf.py build
```

---

## 许可证与相关链接

- 示例应用代码：见各源文件 SPDX（如 `main/main.c` 为 CC0-1.0）
- BSP / 触摸组件：Apache-2.0（以组件仓库为准）
- 第三方组件：遵循各自许可证

相关链接：

- BSP 组件：[viewesmart/bsp_knob_15_md50et](https://components.espressif.com/components/viewesmart/bsp_knob_15_md50et)
- 触摸组件：[viewesmart/esp_lcd_touch_cst820](https://components.espressif.com/components/viewesmart/esp_lcd_touch_cst820)
- 组件源码单仓：[Viewe-esp32-components](https://github.com/VIEWESMART/Viewe-esp32-components)
- ESP-IDF 编程指南：[https://docs.espressif.com/projects/esp-idf/](https://docs.espressif.com/projects/esp-idf/)
- VS Code 插件安装（含 EIM）：[Install ESP-IDF and Tools](https://docs.espressif.com/projects/vscode-esp-idf-extension/en/latest/installation.html)
- EIM 文档：[ESP-IDF Installation Manager](https://docs.espressif.com/projects/idf-im-ui/en/latest/)
- VS Code 插件总览：[Espressif IDF Extension](https://docs.espressif.com/projects/vscode-esp-idf-extension/en/latest/)

欢迎 Issue / PR。若你是第一次接触 ESP-IDF，建议先完整走通本文“环境准备 -> 编译 -> 烧录”三步，再开始改 UI。

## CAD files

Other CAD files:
2D drawings/UEDX46460015-MD50E.dwg

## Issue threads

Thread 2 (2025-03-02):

User data should be placed in SRAM

par-n-go, 2025-03-02:
Following your instructions on how to port and upload the code through the arduino IDE I get this error while trying to compile an example:

```
c:\Projects\screen_test\libraries\ESP32_Display_Panel-bugfix-missing_lcd_load_vendor_config\src\lcd\ESP_PanelLcd.cpp:457:109: error: macro "ESP_PANEL_CHECK_FALSE_RET" requires 4 arguments, but only 1 given
  457 |         ESP_PANEL_CHECK_FALSE_RET((esp_ptr_internal(user_data), false, "User data should be placed in SRAM"));
      |                                                                                                             ^
In file included from c:\Projects\screen_test\libraries\ESP32_Display_Panel-bugfix-missing_lcd_load_vendor_config\src\lcd\ESP_PanelLcd.cpp:9:
c:\Projects\screen_test\libraries\ESP32_Display_Panel-bugfix-missing_lcd_load_vendor_config\src/ESP_PanelLog.h:58: note: macro "ESP_PANEL_CHECK_FALSE_RET" defined here
   58 | #define ESP_PANEL_CHECK_FALSE_RET(x, ret, fmt, ...) do {         \
      |
c:\Projects\screen_test\libraries\ESP32_Display_Panel-bugfix-missing_lcd_load_vendor_config\src\lcd\ESP_PanelLcd.cpp: In member function 'bool ESP_PanelLcd::attachRefreshFinishCallback(std::function<bool(void*)>, void*)':
c:\Projects\screen_test\libraries\ESP32_Display_Panel-bugfix-missing_lcd_load_vendor_config\src\lcd\ESP_PanelLcd.cpp:454:29: error: cannot convert 'std::function<bool(void*)>' to 'const void*'
  454 |             esp_ptr_in_iram(callback), false,
      |                             ^~~~~~~~
      |                             |
      |                             std::function<bool(void*)>
c:\Projects\screen_test\libraries\ESP32_Display_Panel-bugfix-missing_lcd_load_vendor_config\src/ESP_PanelLog.h:59:14: note: in definition of macro 'ESP_PANEL_CHECK_FALSE_RET'
   59 |         if ((x) == false) {                                      \
      |              ^
In file included from C:\Users\valer\AppData\Local\Arduino15\packages\esp32\tools\esp32-arduino-libs\idf-release_v5.3-489d7a2b-v1\esp32s3/include/freertos/FreeRTOS-Kernel/portable/xtensa/include/freertos/portmacro.h:54,
                 from C:\Users\valer\AppData\Local\Arduino15\packages\esp32\tools\esp32-arduino-libs\idf-release_v5.3-489d7a2b-v1\esp32s3/include/freertos/FreeRTOS-Kernel/include/freertos/portable.h:57,
                 from C:\Users\valer\AppData\Local\Arduino15\packages\esp32\tools\esp32-arduino-libs\idf-release_v5.3-489d7a2b-v1\esp32s3/include/freertos/FreeRTOS-Kernel/include/freertos/FreeRTOS.h:69,
                 from C:\Users\valer\AppData\Local\Arduino15\packages\esp32\tools\esp32-arduino-libs\idf-release_v5.3-489d7a2b-v1\esp32s3/include/esp_driver_spi/include/driver/spi_master.h:10,
                 from C:\Users\valer\AppData\Local\Arduino15\packages\esp32\tools\esp32-arduino-libs\idf-release_v5.3-489d7a2b-v1\esp32s3/include/esp_lcd/include/esp_lcd_io_spi.h:11,
                 from C:\Users\valer\AppData\Local\Arduino15\packages\esp32\tools\esp32-arduino-libs\idf-release_v5.3-489d7a2b-v1\esp32s3/include/esp_lcd/include/esp_lcd_panel_io.h:13,
                 from c:\Projects\screen_test\libraries\ESP32_Display_Panel-bugfix-missing_lcd_load_vendor_config\src\lcd\ESP_PanelLcd.cpp:13:
C:\Users\valer\AppData\Local\Arduino15\packages\esp32\tools\esp32-arduino-libs\idf-release_v5.3-489d7a2b-v1\esp32s3/include/esp_hw_support/include/esp_memory_utils.h:41:48: note:   initializing argument 1 of 'bool esp_ptr_in_iram(const void*)'
   41 | inline static bool esp_ptr_in_iram(const void *p) {
      |                                    ~~~~~~~~~~~~^
c:\Projects\screen_test\libraries\ESP32_Display_Panel-bugfix-missing_lcd_load_vendor_config\src\lcd\ESP_PanelLcd.cpp:457:9: error: 'ESP_PANEL_CHECK_FALSE_RET' was not declared in this scope
  457 |         ESP_PANEL_CHECK_FALSE_RET((esp_ptr_internal(user_data), false, "User data should be placed in SRAM"));
      |         ^~~~~~~~~~~~~~~~~~~~~~~~~

exit status 1

Compilation error: exit status 1
```

VIEWESMART, 2025-03-03:
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

Thank you for your feedback. This error is related to the version of the development board you are using. It is recommended that you use version v3.0.6-v3.1.0 for the ESP32 core. Please feel free to provide feedback if you encounter any issues, and I will do my best to help you resolve them.

par-n-go, 2025-03-10:
Thank you, issue is solved

Closed 2025-03-10.

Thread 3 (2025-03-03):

Acccess boot mode

Utstallningsverkstaden, 2025-03-03:
I need to upload a new program in Arduino IDE and it worked the first time, but now it won't upload after the compile is done (serial is working).
How can I access the boot mode pin? Is it possible via the breakout board or do I have to open up the display to reach the esp32 somehow?

VIEWESMART, 2025-03-04:
> I need to upload a new program in Arduino IDE and it worked the first time, but now it won't upload after the compile is done (serial is working). How can I access the boot mode pin? Is it possible via the breakout board or do I have to open up the display to reach the esp32 somehow?

You can try holding down the knob to make it enter the boot mode for burning. Then see if the burning can be successful.

Utstallningsverkstaden, 2025-03-04:
Sadly, that didn't work, nothing happened.

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

The first upload i missed to copy the display driver so it wouldn't run, this is the error message that keeps looping:

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

VIEWESMART, 2025-03-04:
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

Sorry, I want to know if you mean that you can't upload the program or if there are error messages after the program is uploaded.

If you can't burn the program, pressing the button of the knob and then powering on to enter the boot mode for burning as I mentioned before should be feasible. If it doesn't work, we can also use UART for burning.

If the code can be uploaded normally, but the device keeps restarting, I see that the error messages are:
08:42:31.545 -> [E][Panel]esp_panel_board.cpp:0250: Init failed
08:42:31.545 -> [E][LvPort]lvgl_port_v8.cpp:0740: Invalid LCD device
08:42:31.545 -> [E][LvPort]lvgl_port_v8.cpp:0812: LVGL mutex is not initialized
It seems that some files are missing, or the libraries are not quite compatible.

I hope to get more detailed information so that I can help you.

Utstallningsverkstaden, 2025-03-04:
Now I got it to work, when held down knob before powering on, Previously I held it down after the compile was done, when going into upload. Thank you for mentioning that!

VIEWESMART, 2025-03-04:
> Now I got it to work, when held down knob before powering on, Previously I held it down after the compile was done, when going into upload. Thank you for mentioning that!

I'm very glad to hear this news. I'm really sorry for not mentioning this before, which has wasted your time.

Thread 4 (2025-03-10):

platformio example missing

par-n-go, 2025-03-10:
Do you have platformio example for this screen?
It is written in the documentation but files are not present

VIEWESMART, 2025-03-12:
> Do you have platformio example for this screen? It is written in the documentation but files are not present

Sorry for the late reply. I haven't provided PlatformIO for now, but I will definitely provide it. You may need to wait a bit. However, it is very similar to Arduino, so you can have a try first. I will let you know when I'm ready.

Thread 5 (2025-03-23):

Adapter Board Information

jon68z, 2025-03-23:
Hello, can you please provide information on the adapter board? A schematic and physical drawing would be very much appreciated,

Thanks!

VIEWESMART, 2025-03-24:
> Hello, can you please provide information on the adapter board? A schematic and physical drawing would be very much appreciated,
>
> Thanks!

I'm very sorry. We haven't created a schematic diagram because its principle is simple, but we will add it later. I can provide you with some information about its interfaces, as shown in the following picture:

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

The position of J2 in the picture is the connection location of the flat cable. The internal pins connected are shown in the following picture:

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

The corresponding pin information below J2 is shown in the following picture:

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

VIEWESMART, 2025-03-24:
> Hello, can you please provide information on the adapter board? A schematic and physical drawing would be very much appreciated,
>
> Thanks!

I'm very sorry. We haven't created a schematic diagram because its principle is simple, but we will add it later. I can provide you with some information about its interfaces, The physical picture is as follows:

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

The position of J2 in the picture is the connection location of the flat cable. The internal pins connected are shown in the following picture:

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

The corresponding pin information below J2 is shown in the following picture:

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

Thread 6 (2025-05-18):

Wrong drivers ?

soapyapi, 2025-05-18:
Hello,

Can you explain how the implementation of the driver works in your code ? Why do you use sh8601 and manually configure it with led arrays instead of of co5300 and a proper qspi setup ? I might work in the example code, but has proven very hard to change/port, especially with newer lvgl releases (9+).

Thank you very much,

VIEWESMART, 2025-05-19:
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

Hello，
Because there is no co5300 driver in the official driver library for the time being, it is used to modify the compatible driver after the initialization instruction instead. It is also QSPI, which does not affect its work. As far as the current example is concerned, it can only be implemented based on lvgl v8, because we are porting v8 in the lvgl_port.

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

qwerkus-1, 2025-05-20:
Thank you for your reply. Actually there is a co5300 driver available here: https://components.espressif.com/components/kodediy/esp_lcd_co5300 nnd it works in lvgl 8.3.
I'm trying to port it to lvgl 9 without success so far. Display turns on but colors are wront a buggy. Can you help me out here?

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

Here is my code:

`#include <stdio.h>
#include <unistd.h>
#include <sys/lock.h>
#include <sys/param.h>
#include "freertos/FreeRTOS.h"
#include "freertos/task.h"
#include "driver/gpio.h"
#include "driver/spi_master.h"
#include "esp_timer.h"
#include "esp_lcd_panel_io.h"
#include "esp_lcd_panel_vendor.h"
#include "esp_lcd_panel_ops.h"
#include "esp_err.h"
#include "esp_log.h"
#include "lvgl.h"
#include "esp_lcd_co5300.h"
#include "ui.h"
#include "lv_examples.h"

#define LCD_HOST               (SPI2_HOST)
#define PIN_NUM_LCD_CS         (GPIO_NUM_12)
#define PIN_NUM_LCD_PCLK       (GPIO_NUM_10)
#define PIN_NUM_LCD_DATA0      (GPIO_NUM_13)
#define PIN_NUM_LCD_DATA1      (GPIO_NUM_11)
#define PIN_NUM_LCD_DATA2      (GPIO_NUM_14)
#define PIN_NUM_LCD_DATA3      (GPIO_NUM_9)
#define PIN_NUM_LCD_RST        (GPIO_NUM_8)
#define PIN_NUM_BK_LIGHT       (GPIO_NUM_17)
#define LCD_H_RES              471
#define LCD_V_RES              466
#define LCD_BIT_PER_PIXEL      16
#define LCD_BK_LIGHT_ON_LEVEL  1

#define LVGL_DRAW_BUF_LINES    20 // number of display lines in each draw buffer
#define LVGL_TICK_PERIOD_MS    2
#define LVGL_TASK_MAX_DELAY_MS 500
#define LVGL_TASK_MIN_DELAY_MS 1000 / CONFIG_FREERTOS_HZ
#define LVGL_TASK_STACK_SIZE   (4 * 1024)
#define LVGL_TASK_PRIORITY     2

static const char *TAG = "main";

// Custom initalizations according to vendor's example - doesn't seem to make a difference
static const co5300_lcd_init_cmd_t lcd_init_cmds[] = {
    {0xFE, (uint8_t []){0x00}, 0, 0},
    {0xC4, (uint8_t []){0x80}, 1, 0},
    {0x3A, (uint8_t []){0x55}, 1, 0},
    {0x35, (uint8_t []){0x00}, 0, 10},
    {0x53, (uint8_t []){0x20}, 1, 10},
    {0x51, (uint8_t []){0xFF}, 1, 10},
    {0x63, (uint8_t []){0xFF}, 1, 10},
    //{0x2A, (uint8_t []){0x00,0x06,0x01,0xD7}, 4, 0},
    {0x2A, (uint8_t []){0x00,0x06,0x01,0xDD}, 4, 0},
    {0x2B, (uint8_t []){0x00,0x00,0x01,0xD1}, 4, 0},
    {0x11, (uint8_t []){0x00}, 0, 60},
    {0x29, (uint8_t []){0x00}, 0, 0},
};
// LVGL library = not thread-safe, so we will call LVGL APIs from different tasks and use a mutex to protect it
static _lock_t lvgl_api_lock;

static esp_lcd_panel_handle_t panel_handle = NULL;

static bool notify_lvgl_flush_ready(esp_lcd_panel_io_handle_t panel_io, esp_lcd_panel_io_event_data_t *edata, void *user_ctx)
{
    lv_display_t *disp = (lv_display_t *)user_ctx;
    lv_disp_flush_ready(disp);
    return false; // was true ?
}

void lvgl_flush_cb(lv_display_t *disp, const lv_area_t *area, uint8_t *color_map) {
    esp_lcd_panel_draw_bitmap(panel_handle, area->x1, area->y1, area->x2 + 1, area->y2 + 1, color_map);
    // flush_ready is called from the notify callback
}

static void increase_lvgl_tick(void *arg) {
    lv_tick_inc(2);
}

void lvgl_display_init(void) {
    gpio_config_t bk_gpio_config = {
        .mode = GPIO_MODE_OUTPUT,
        .pin_bit_mask = 1ULL << PIN_NUM_BK_LIGHT
    };
    ESP_ERROR_CHECK(gpio_config(&bk_gpio_config));
    gpio_set_level(PIN_NUM_BK_LIGHT, LCD_BK_LIGHT_ON_LEVEL);
    ESP_LOGI(TAG, "Backlight turned on");

    lv_display_t * disp = lv_display_create(LCD_H_RES, LCD_V_RES);
    lv_display_set_color_format(disp, LV_COLOR_FORMAT_RGB565);
    lv_display_set_flush_cb(disp, lvgl_flush_cb);

    // Double buffer
    size_t buf_size = (LCD_H_RES * LCD_V_RES / 10) * 2;  // 2 bytes per pixel for RGB565
    uint8_t *buf1 = heap_caps_aligned_alloc(64, buf_size, MALLOC_CAP_DMA);
    uint8_t *buf2 = heap_caps_aligned_alloc(64, buf_size, MALLOC_CAP_DMA);
    assert(buf1);
    assert(buf2);

    lv_display_set_buffers(disp, buf1, buf2, buf_size, LV_DISPLAY_RENDER_MODE_PARTIAL);

    ESP_LOGI(TAG, "Initialize QSPI bus");
    const spi_bus_config_t buscfg = CO5300_PANEL_BUS_QSPI_CONFIG(
        PIN_NUM_LCD_PCLK,
        PIN_NUM_LCD_DATA0,
        PIN_NUM_LCD_DATA1,
        PIN_NUM_LCD_DATA2,
        PIN_NUM_LCD_DATA3,
        LCD_H_RES * LCD_V_RES * LCD_BIT_PER_PIXEL / 8
    );
    ESP_ERROR_CHECK(spi_bus_initialize(LCD_HOST, &buscfg, SPI_DMA_CH_AUTO));

    ESP_LOGI(TAG, "Install panel IO");
    esp_lcd_panel_io_handle_t io_handle = NULL;
    const esp_lcd_panel_io_spi_config_t io_config = CO5300_PANEL_IO_QSPI_CONFIG(PIN_NUM_LCD_CS, notify_lvgl_flush_ready, (void *)disp);
    ESP_ERROR_CHECK(esp_lcd_new_panel_io_spi((esp_lcd_spi_bus_handle_t)LCD_HOST, &io_config, &io_handle));

    ESP_LOGI(TAG, "Install CO5300 panel driver");
    //esp_lcd_panel_handle_t panel_handle = NULL; Declared globally at the beginning
    co5300_vendor_config_t vendor_config = {
        .init_cmds = lcd_init_cmds,
        .init_cmds_size = sizeof(lcd_init_cmds) / sizeof(co5300_lcd_init_cmd_t),
    };
    const esp_lcd_panel_dev_config_t panel_config = {
        .reset_gpio_num = PIN_NUM_LCD_RST,
        .rgb_ele_order = LCD_RGB_ELEMENT_ORDER_RGB,     // Implemented by LCD command `36h`
        .bits_per_pixel = LCD_BIT_PER_PIXEL,    // Implemented by LCD command `3Ah` (16/18/24)
        .vendor_config = (void *)&vendor_config,
    };
    ESP_ERROR_CHECK(esp_lcd_new_panel_co5300(io_handle, &panel_config, &panel_handle));

    ESP_ERROR_CHECK(esp_lcd_panel_reset(panel_handle));
    ESP_ERROR_CHECK(esp_lcd_panel_init(panel_handle));
    ESP_ERROR_CHECK(esp_lcd_panel_disp_on_off(panel_handle, true));

     ESP_LOGI(TAG, "Install LVGL tick timer");
    // Tick interface for LVGL (using esp_timer to generate 2ms periodic event)
    const esp_timer_create_args_t lvgl_tick_timer_args = {
        .callback = &increase_lvgl_tick,
        .name = "lvgl_tick"
    };
    esp_timer_handle_t lvgl_tick_timer = NULL;
    ESP_ERROR_CHECK(esp_timer_create(&lvgl_tick_timer_args, &lvgl_tick_timer));
    ESP_ERROR_CHECK(esp_timer_start_periodic(lvgl_tick_timer, LVGL_TICK_PERIOD_MS * 1000));

}

static void lvgl_port_task(void *arg)
{
    ESP_LOGI(TAG, "Starting LVGL task");
    uint32_t time_till_next_ms = 0;
    while (1) {
        _lock_acquire(&lvgl_api_lock);
        time_till_next_ms = lv_timer_handler();
        _lock_release(&lvgl_api_lock);
        // in case of triggering a task watch dog time out
        time_till_next_ms = MAX(time_till_next_ms, LVGL_TASK_MIN_DELAY_MS);
        // in case of lvgl display not ready yet
        time_till_next_ms = MIN(time_till_next_ms, LVGL_TASK_MAX_DELAY_MS);
        usleep(1000 * time_till_next_ms);
    }
}

void app_main(void) {
    lv_init();
    lvgl_display_init();

    ESP_LOGI(TAG, "Create LVGL task");
    xTaskCreate(lvgl_port_task, "LVGL", LVGL_TASK_STACK_SIZE, NULL, LVGL_TASK_PRIORITY, NULL);

    ESP_LOGI(TAG, "Lock & Create Spinner");
    // Lock the mutex due to the LVGL APIs are not thread-safe
    _lock_acquire(&lvgl_api_lock);

    /*Create a spinner*/
    lv_obj_t * spinner = lv_spinner_create(lv_screen_active());
    lv_obj_set_size(spinner, 300, 300);
    lv_obj_center(spinner);
    lv_spinner_set_anim_params(spinner, 10000, 200);

    _lock_release(&lvgl_api_lock);
}
`

VIEWESMART, 2025-05-20:
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

Yes, I know this driver, but it does not belong to the official Espressif driver library, so it cannot be called in the display_panel, so it is not used.
For the color problem you want to use lvgl v9, it should be that a certain parameter is not set properly. I need to configure it myself, and I will reply to you tomorrow, China time.

qwerkus-1, 2025-05-20:
Ok wating for your reply. Here is my idf_component.yml for lvgl 9 on your device:
`
dependencies:
  ## Required IDF version
  idf:
    version: '>=4.1.0'
  lvgl/lvgl: '*'
  espressif/knob: '*'
  espressif/button: '*'
  kodediy/esp_lcd_co5300: '*'
  kodediy/esp_lcd_touch_cst820: '*'
`

VIEWESMART, 2025-05-21:
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

Are you using idf? Oak, that's much easier to handle.

qwerkus-1, 2025-05-22:
Any update on this ? LVGL 9 would be really nice on this display.

VIEWESMART, 2025-05-22:
> Any update on this ? LVGL 9 would be really nice on this display.

Yes, I'm already working on it. It may be delayed. I'll give it to you tomorrow at the latest.

VIEWESMART, 2025-05-24:
> Any update on this ? LVGL 9 would be really nice on this display.

I have synced my latest content to GitHub, linking to: https://github.com/VIEWESMART/UEDX46460015-MD50ESP32-1.5inch-Touch-Knob-Display/tree/main/examples/ESP-IDF/1.5inch_lvgl_v9_port

There is no problem with the color, because of the time relationship in the coordinate alignment you need to refer to the v8 configuration rounder_cb adjustment, you can also refer to here: https://github.com/Lzw655/esp-bsp/blob/d99913fd6a186a842a81b1543e1b3b6f146f1462/components/esp_lvgl_port/src/lvgl9/esp_lvgl_port_disp.c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

We didn't have time to deal with this piece, and we will further improve it in the future.

qwerkus-1, 2025-05-24:
Thank you for your efforts. Color correct now but lvgl9 animations are still slow and glitchy - see picture. Also, why do you include HF_ws2812 - there is no led strip on this device.

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

qwerkus-1, 2025-05-24:
Not sure I'm following what you're trying to do: if you want to use lvgl_port, it makes the code simpler, but there is no option for a callback function so you cannot implement rounders. If you want to implement rounds, you need to configure lvgl manually and you don't need lvgl port. The esb-bp link you sent me seems unnecessary complex: they call lvgl_port and than configure the display manually !?

VIEWESMART, 2025-06-19:
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

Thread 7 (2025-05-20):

Wrong Blacklight gpio specified in the readme - please fix it.

qwerkus-1, 2025-05-20:
Backlight gpio is 17 not 7 on this device, otherwise it won't work

VIEWESMART, 2025-05-21:
> Backlight gpio is 17 not 7 on this device, otherwise it won't work

Yes, it's gpio17, thanks for pointing it out.

Closed 2025-05-21.

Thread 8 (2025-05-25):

[Question] How to upload firmware

thiagokabral, 2025-05-25:
Hello,

I have purchased the ESP32 1.5 inch Touch Knob Display (UEDX46460015-MD50ESP32) and I’m trying to develop using the examples provided in this repository. However, I have some doubts about the correct procedure for uploading the firmware to the device.

My main question is:

How can I upload the firmware to the board?
Does the USB port on the board work only for power, or is it also used for uploading the firmware?

Context:

I’m using an ESP32 DevKit connected to the TX, RX, 5V, and GND pins of the board, trying to upload the firmware, but without success so far.

The documentation is not very clear about the proper upload procedure (whether I need an external USB-UART adapter, the ESP32 DevKit, JTAG, or another method).

Could you please clarify:

What is the correct procedure to upload firmware to this board?

What hardware is required (USB-TTL adapter, DevKit, JTAG, or anything else)?

Is there a guide or step-by-step tutorial for this process?

Thank you very much for your support

VIEWESMART, 2025-05-26:
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

Hello，
No additional hardware is required. The steps are as follows:
Connect the device's 10-pin FPC cable to the J2 of the green adapter board, as shown below:

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

2. Press and hold the button in the middle of the knob first, then plug in the USB (enter the burning mode, the screen will not display any content after plugging in the USB), plug it in and release the button to burn.

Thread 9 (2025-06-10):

Build failure on Windows 11 – missing `toolchain-riscv32-esp` & errors in `ESP32_Display_Panel-bugfix-missing_lcd_load_vendor_config`

Argeento, 2025-06-10:
### Environment
- **OS:** Windows 11 (amd64)
- **PlatformIO:** Core 6.1.18, Home 3.4.4

---

### Description
When running `platformio run --target upload` on Windows 11, PlatformIO first fails to fetch `espressif/toolchain-riscv32-esp @ 13.2.0+20240530` (no Windows package). After overriding to `platformio/toolchain-riscv32-esp@~14.2.0`, compilation of `ESP32_Display_Panel-bugfix-missing_lcd_load_vendor_config` fails with numerous C++ errors in `ledc_timer_config_t` and macro expansions (see logs).

---

### Logs / Error Output

```text
UnknownPackageError: Could not find the package with 'espressif/toolchain-riscv32-esp @ 13.2.0+20240530'
 requirements for your system 'windows_amd64'

...

lib/ESP32_Display_Panel-bugfix-missing_lcd_load_vendor_config/src/backlight/ESP_PanelBacklight.cpp:18:92:
 error: no matching function for call to
 'ledc_timer_config_t::ledc_timer_config_t(<brace-enclosed initializer list>)'

...

lib/ESP32_Display_Panel-bugfix-missing_lcd_load_vendor_config/src/bus/ESP_PanelBus.cpp:31:49:
 error: expected ')' before 'PRIx32'

...

lib/ESP32_Display_Panel-bugfix-missing_lcd_load_vendor_config/src/bus/ESP_PanelBus.cpp:31:49: error: expected ')' before 'PRIx32'

...

lib/ESP32_Display_Panel-bugfix-missing_lcd_load_vendor_config/src/bus/RGB.h:90:24: error: 'LCD_CLK_SRC_DEFAULT' was not declared in this scope

...and more
```

### Questions

1) Is the missing RISC-V toolchain package a known Windows/PlatformIO issue?
2) Is the bugfix-missing_lcd_load_vendor_config branch still maintained and compatible with arduinoespressif32 3.2.x on ESP32-S3?
3) What combination of toolchain and library version is recommended for a working build on Windows?

Argeento, 2025-06-10:
Thank you for your quick answer 🚀

Any tips on how to easily display a single value centered on the screen? This is the only feature my product needs, but I'm struggling - even with the help of ChatGPT

Argeento, 2025-06-10:
I've manage to compile and run a simple example with `ESP32_Display_Panel v1.0.2`, but there is another problem:

```
No default board configuration detected. There are three ways to provide a default configuration:
        1. Use the `esp_panel_board_supported_conf.h` file to enable a supported board.
        2. Use the `esp_panel_board_custom_conf.h` file to define a custom board
[E][Panel][esp_panel_board.cpp:0250](begin): Init failed
```

[Known devices list](https://github.com/esp-arduino-libs/ESP32_Display_Panel/blob/master/esp_panel_board_supported_conf.h#L126-L146) is missing my model `UEDX46460015-MD50E`

Can you provide a `esp_panel_drivers_conf.h` and `esp_panel_board_custom_conf.h` for the  `UEDX46460015-MD50E`?

Closed 2025-06-10.

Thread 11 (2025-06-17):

uart + usb ?

qwerkus-1, 2025-06-17:
Hello,

Is it possible to use both uart and usb on this pcb ? They seem routed to different pins, but whenever I enable uart in my code, I lose u1 connector on the dev board which is really annoying for debugging. Thanks.

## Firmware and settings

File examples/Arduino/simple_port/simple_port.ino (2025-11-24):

/**
 * Detailed usage of the example can be found in the [README.md](./README.md) file
 */

#include <Arduino.h>
#include <esp_display_panel.hpp>
#include <lvgl.h>
#include "lvgl_v8_port.h"

#include <ESP_Knob.h>
#include <Button.h>
#include <ui.h>

/**
/* To use the built-in examples and demos of LVGL uncomment the includes below respectively.
 * You also need to copy `lvgl/examples` to `lvgl/src/examples`. Similarly for the demos `lvgl/demos` to `lvgl/src/demos`.
 */
// #include <demos/lv_demos.h>
// #include <examples/lv_examples.h>

using namespace esp_panel::drivers;
using namespace esp_panel::board;

/*if you use BOARD_VIEWE_UEDX46460015_MD50ET or UEDX48480021_MD80E/T,please open it*/
#define GPIO_NUM_KNOB_PIN_A     6
#define GPIO_NUM_KNOB_PIN_B     5
#define GPIO_BUTTON_PIN         GPIO_NUM_0

/*Knob event definition*/
ESP_Knob *knob;
void onKnobLeftEventCallback(int count, void *usr_data)
{
    // Serial.printf("Detect left event, count is %d\n", count);
    lvgl_port_lock(-1);
    LVGL_knob_event((void*)KNOB_LEFT);
    lvgl_port_unlock();
}

void onKnobRightEventCallback(int count, void *usr_data)
{
    // Serial.printf("Detect right event, count is %d\n", count);
    lvgl_port_lock(-1);
    LVGL_knob_event((void*)KNOB_RIGHT);
    lvgl_port_unlock();
}

static void SingleClickCb(void *button_handle, void *usr_data) {
    // Serial.println("Button Single Click");
    lvgl_port_lock(-1);
    LVGL_button_event((void*)BUTTON_SINGLE_CLICK);
    lvgl_port_unlock();
}
static void DoubleClickCb(void *button_handle, void *usr_data)
{
    // Serial.println("Button Double Click");
}
static void LongPressStartCb(void *button_handle, void *usr_data) {
    // Serial.println("Button Long Press Start");
    lvgl_port_lock(-1);
    LVGL_button_event((void*)BUTTON_LONG_PRESS_START);
    lvgl_port_unlock();
}

void setup()
{
    Serial.begin(115200);

    Serial.println("Initializing board");
    // esp_log_level_set("*", ESP_LOG_NONE);
  
  // Initialize UART0
    // MySerial.begin(9600, SERIAL_8N1, RX_PIN, TX_PIN);
    Board *board = new Board();
    board->init();
#if LVGL_PORT_AVOID_TEARING_MODE
    auto lcd = board->getLCD();
    // When avoid tearing function is enabled, the frame buffer number should be set in the board driver
    lcd->configFrameBufferNumber(LVGL_PORT_DISP_BUFFER_NUM);
#if ESP_PANEL_DRIVERS_BUS_ENABLE_RGB && CONFIG_IDF_TARGET_ESP32S3
    auto lcd_bus = lcd->getBus();
    /**
     * As the anti-tearing feature typically consumes more PSRAM bandwidth, for the ESP32-S3, we need to utilize the
     * "bounce buffer" functionality to enhance the RGB data bandwidth.
     * This feature will consume `bounce_buffer_size * bytes_per_pixel * 2` of SRAM memory.
     */
    if (lcd_bus->getBasicAttributes().type == ESP_PANEL_BUS_TYPE_RGB) {
        static_cast<BusRGB *>(lcd_bus)->configRGB_BounceBufferSize(lcd->getFrameWidth() * 10);
    }
#endif
#endif
    assert(board->begin());

    Serial.println("Initializing LVGL");
    lvgl_port_init(board->getLCD(), board->getTouch());

    /*knob initialization*/
    Serial.println("Initialize Knob device");
    knob = new ESP_Knob(GPIO_NUM_KNOB_PIN_A, GPIO_NUM_KNOB_PIN_B);
    knob->begin();
    knob->attachLeftEventCallback(onKnobLeftEventCallback);
    knob->attachRightEventCallback(onKnobRightEventCallback);

    Serial.println("Initialize Button device");
    Button *btn = new Button(GPIO_BUTTON_PIN, false);
    btn->attachSingleClickEventCb(&SingleClickCb, NULL);
    btn->attachDoubleClickEventCb(&DoubleClickCb, NULL);
    btn->attachLongPressStartEventCb(&LongPressStartCb, NULL);

    Serial.println("Creating UI");
    /* Lock the mutex due to the LVGL APIs are not thread-safe */
    lvgl_port_lock(-1);

    /**
     * Create the simple labels
     */

    /**
     * Try an example. Don't forget to uncomment header.
     * See all the examples online: https://docs.lvgl.io/master/examples.html
     * source codes: https://github.com/lvgl/lvgl/tree/e7f88efa5853128bf871dde335c0ca8da9eb7731/examples
     */
    //  lv_example_btn_1();

    /**
     * Or try out a demo.
     * Don't forget to uncomment header and enable the demos in `lv_conf.h`. E.g. `LV_USE_DEMO_WIDGETS`
     */
    // lv_demo_widgets();
    // lv_demo_benchmark();
    // lv_demo_music();
    // lv_demo_stress();
    ui_init();
    /* Release the mutex */
    lvgl_port_unlock();
}

void loop()
{
    Serial.println("IDLE loop");
    delay(1000);
}

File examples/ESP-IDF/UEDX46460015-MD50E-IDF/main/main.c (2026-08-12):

/*
 * SPDX-FileCopyrightText: 2023-2026 Espressif Systems (Shanghai) CO LTD
 *
 * SPDX-License-Identifier: CC0-1.0
 *
 * UEDX46460015-MD50E: CO5300 QSPI + CST820 + esp_lvgl_adapter
 * Board bring-up uses registry component viewesmart/bsp_knob_15_md50et.
 */

#include "esp_log.h"
#include "esp_err.h"
#include "bsp_knob_15_md50et.h"
#include "ui.h"

static const char *TAG = "example";

void app_main(void)
{
    bsp_knob_15_md50et_handles_t handles = {0};
    ESP_ERROR_CHECK(bsp_knob_15_md50et_init(&handles));
    ESP_LOGI(TAG, "disp=%p touch=%p panel=%p", handles.disp, handles.touch, handles.panel);

    bsp_knob_15_md50et_register_knob_cb(LVGL_knob_event);
    bsp_knob_15_md50et_register_button_cb(LVGL_button_event);

    ESP_LOGI(TAG, "Display UI");
    if (bsp_knob_15_md50et_lock(-1) == ESP_OK) {
        ui_init();
        bsp_knob_15_md50et_unlock();
    }
}

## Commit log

2025-11-24 Revise README for improved framework setup instructions
    Updated the README to enhance the structure and clarity of the software framework configuration, installation instructions, and example usage for various IDEs.
2025-11-24 Document changes to board macro definitions
    Updated README to reflect changes in esp_panel_board_supported_conf.h.
2025-11-24 Fix: The type mismatch issue in the UI library under the Arduino environment
    [simple_port.ino]
2026-01-09 fix: The display alignment issue of 1.5 in lvgl v9
    [partitions.csv]
2026-01-30 Update board setting from ESP32C3 to ESP32S3
2026-05-11 Add 2D drawings, update the specification document, and fix code errors occurring in esp-idf v5.5.3 version
    [UEDX46460015-MD50E.dwg]
2026-05-16 Update schematic section in README_CN.md
    Removed the old schematic image section and added a new link to the schematic.
2026-05-16 Remove schematic image from README
2026-08-12 Update the IDF example, switch to BSP driver, and add usage instructions.
2026-08-12 Revise setup sections in README_CN.md
    Updated section headers and added detailed steps for ESP-IDF and Arduino setups.
